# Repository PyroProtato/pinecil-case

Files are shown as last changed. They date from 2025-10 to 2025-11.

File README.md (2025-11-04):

# Pinecil Case






A 3D printed case for my pinecil with a few unique features! Uses magnets for closing, paper clips as hinges, and the rest is fully 3D-printed.

I wanted to make this project because I haven't really experimented with snap-fit parts, clean designs, and printabiility in my 3D models thus far since most of them are practical. So, to practice these skills, I decided to design and make a case for my pinecil (which I needed to do anyway). I specifically ensured that no weird parts were used (besides filament only paper clips and magnets). 

 ## BOM:
- (1x) Case Top [3D-Printed]
- (1x) Case Bottom [3D-Printed]
- (2x) Pinecil Clip [3D-Printed]
- (1x) Pinecil Logo [3D-Printed]
- (1x) Pinecil Border [3D-Printed]
- (1x) Standard Paper Clip
- (4-8x) 5mm diameter 2.8mm height magnet

 ## Creation Instructions
3D print all of the STEP files located in the 3DPRINT folder. Make sure that the layer height is set to 0.1mm for the case top and case bottom. Afterwards, assemble by cutting, inserting, and bending paper clips in the hinges, gluing logo and border onto the top case, gluing magnets into the provided holes, and gluing the clips into the indentations on the bottom case. Let it dry, and then the case is done!

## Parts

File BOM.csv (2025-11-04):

Amount | Part Name | Fabrication Method
(1x) | Case Top | [3D-Printed]
(1x) | Case Bottom | [3D-Printed]
(2x) | Pinecil Clip | [3D-Printed]
(1x) | Pinecil Logo | [3D-Printed]
(1x) | Pinecil Border | [3D-Printed]
(1x) | Standard Paper Clip | N/A
(4-8x) | 5mm diameter 2.8mm height magnet | N/A

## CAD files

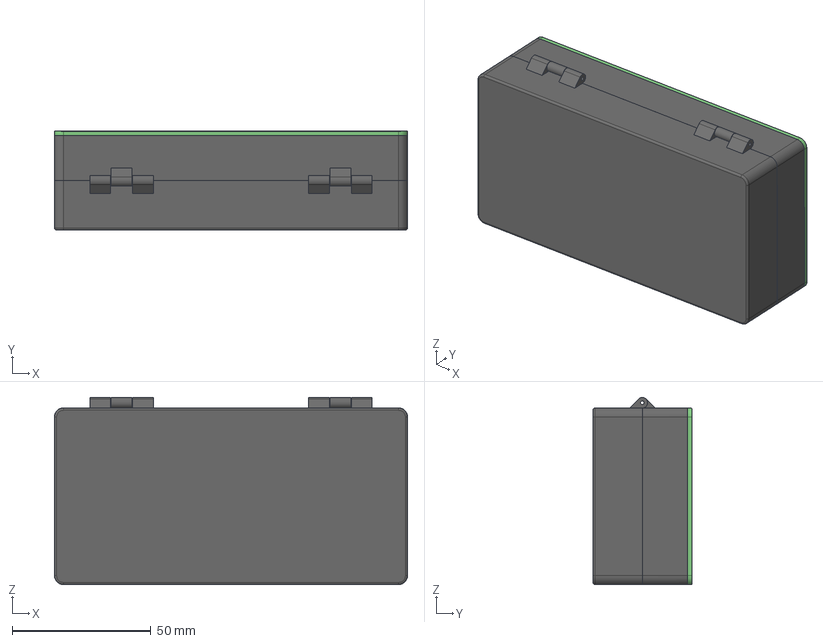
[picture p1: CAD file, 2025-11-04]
PinecilCaseASM.stp
127.0 x 35.7 x 67.3 mm
PinecilCaseBottom
Pinecil Clip x 2
PinecilCaseTop
PinecilLogo
PinecilCaseBorder

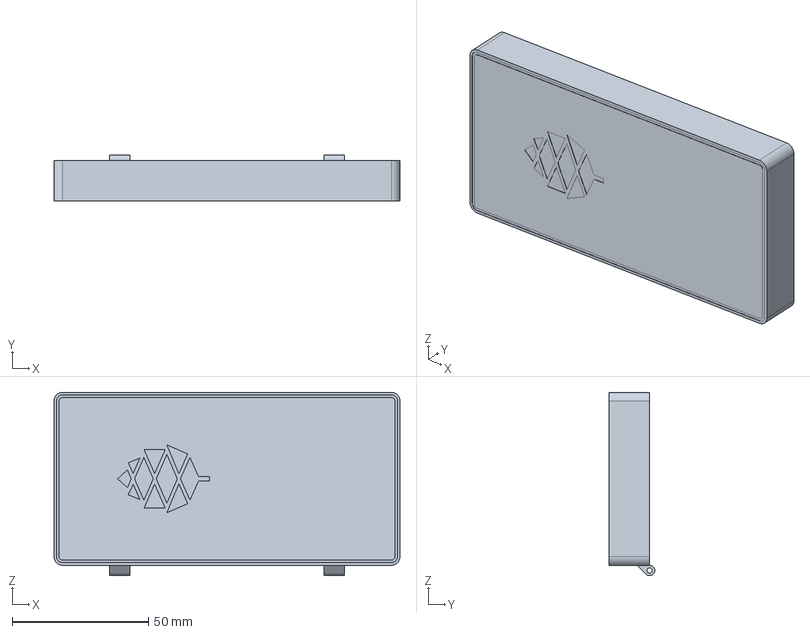
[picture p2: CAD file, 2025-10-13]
3D Print Tests/PinecilCaseTop.stp
127.0 x 16.8 x 67.3 mm

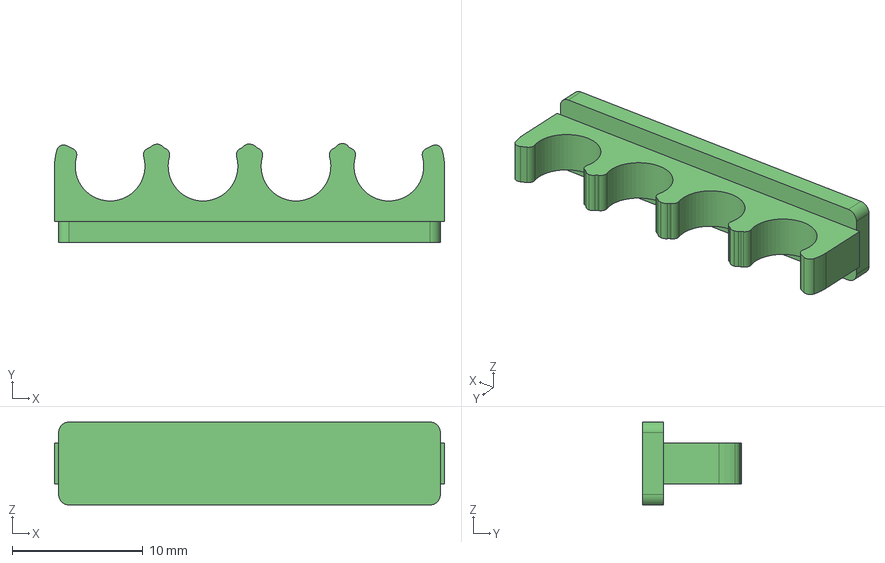
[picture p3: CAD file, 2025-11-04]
3DPRINT/Pinecil Clip.stp
29.8 x 7.57 x 6.35 mm

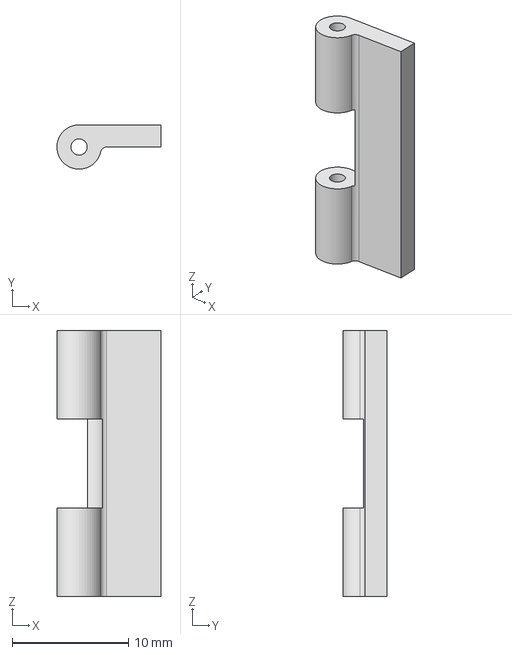
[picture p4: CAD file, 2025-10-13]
Hinge Test/3dp/outerhinge3.stp
8.95 x 3.81 x 22.9 mm

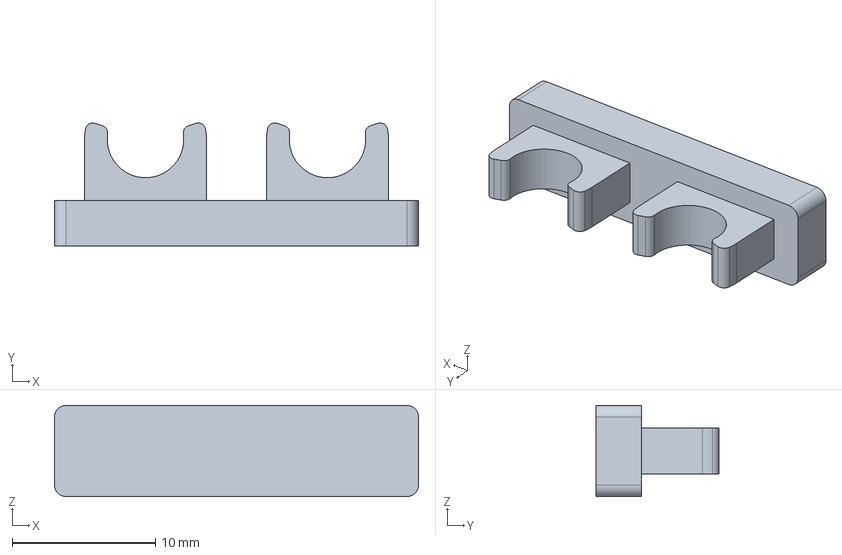
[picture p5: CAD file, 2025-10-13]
3D Print Tests/Pinecil Clip v6.stp
25.4 x 8.58 x 6.35 mm

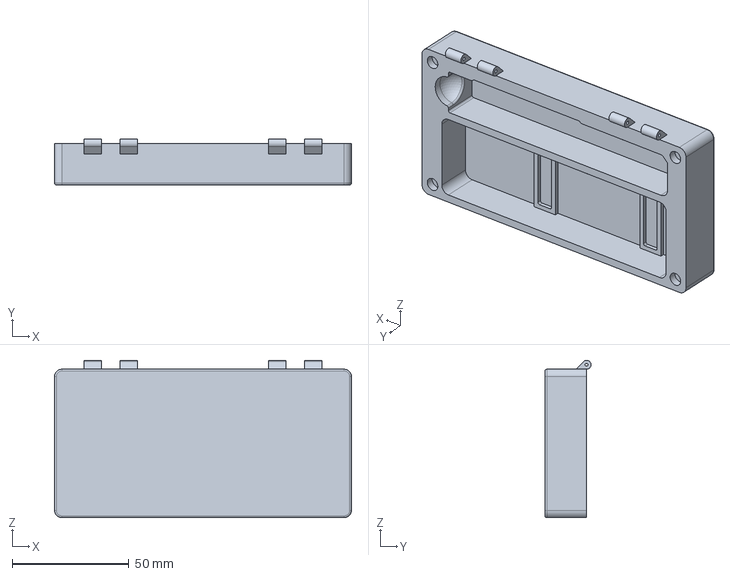
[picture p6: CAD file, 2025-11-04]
3DPRINT/PinecilCaseBottom.stp
127.0 x 19.7 x 67.3 mm

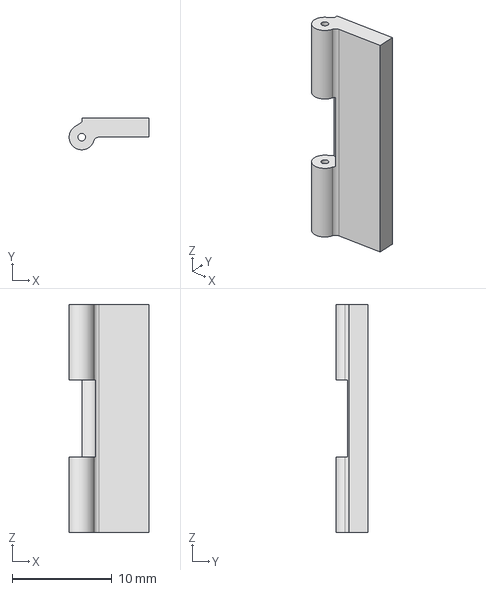
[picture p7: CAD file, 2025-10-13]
Hinge Test/3dp/outerhinge.stp
8.00 x 3.17 x 22.9 mm

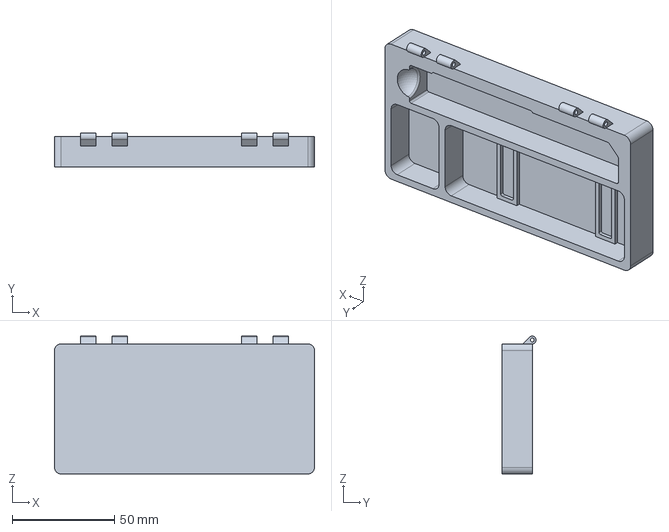
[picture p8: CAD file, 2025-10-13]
3D Print Tests/PinecilCaseBottom.stp
127.0 x 16.8 x 67.3 mm

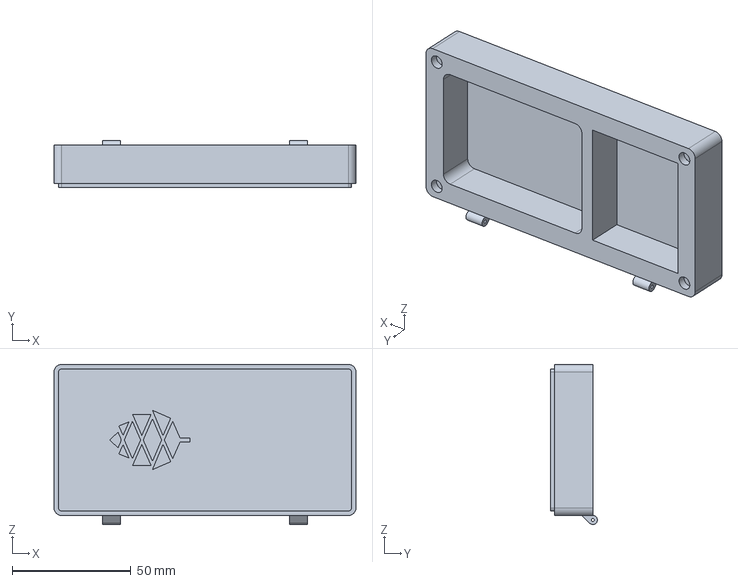
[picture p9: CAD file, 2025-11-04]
3DPRINT/PinecilCaseTop.stp
127.0 x 19.7 x 67.3 mm

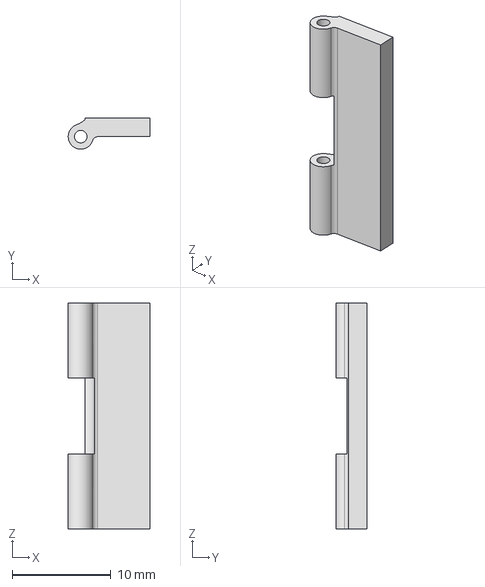
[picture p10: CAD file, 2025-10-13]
Hinge Test/3dp/outerhinge2.stp
8.25 x 3.17 x 22.9 mm

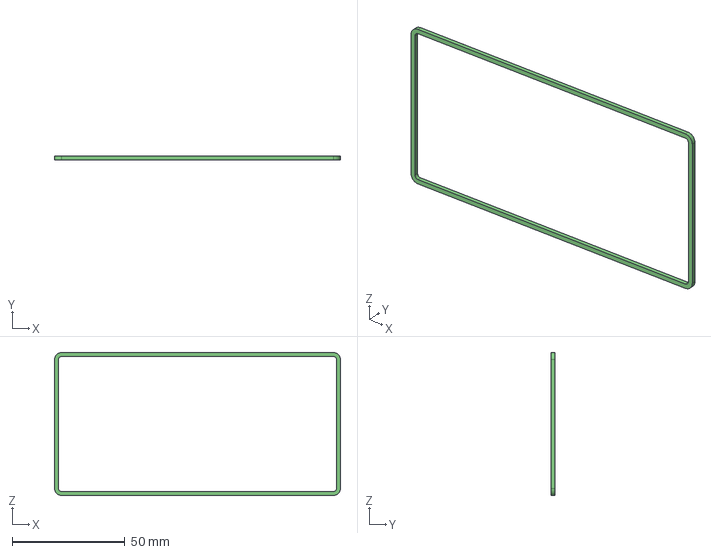
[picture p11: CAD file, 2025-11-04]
3DPRINT/PinecilCaseBorder.stp
127.0 x 1.59 x 63.5 mm

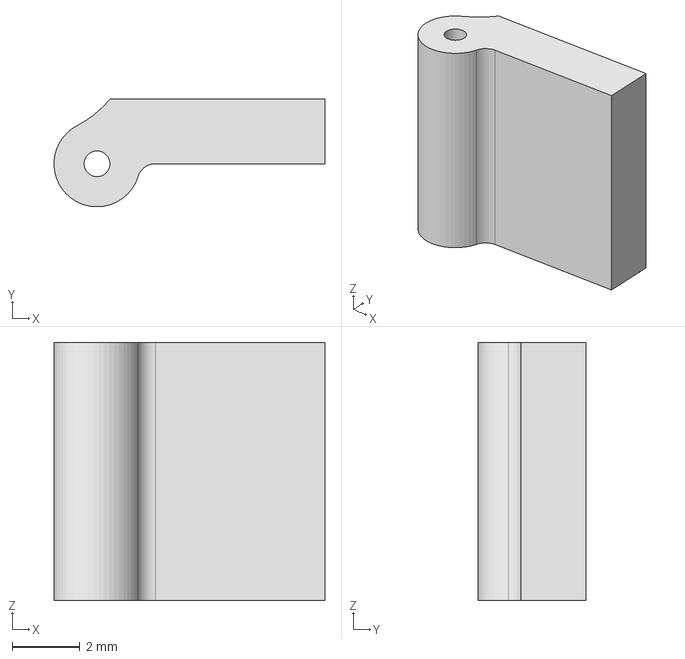
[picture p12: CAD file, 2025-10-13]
Hinge Test/3dp/innerhinge.stp
8.00 x 3.17 x 7.62 mm

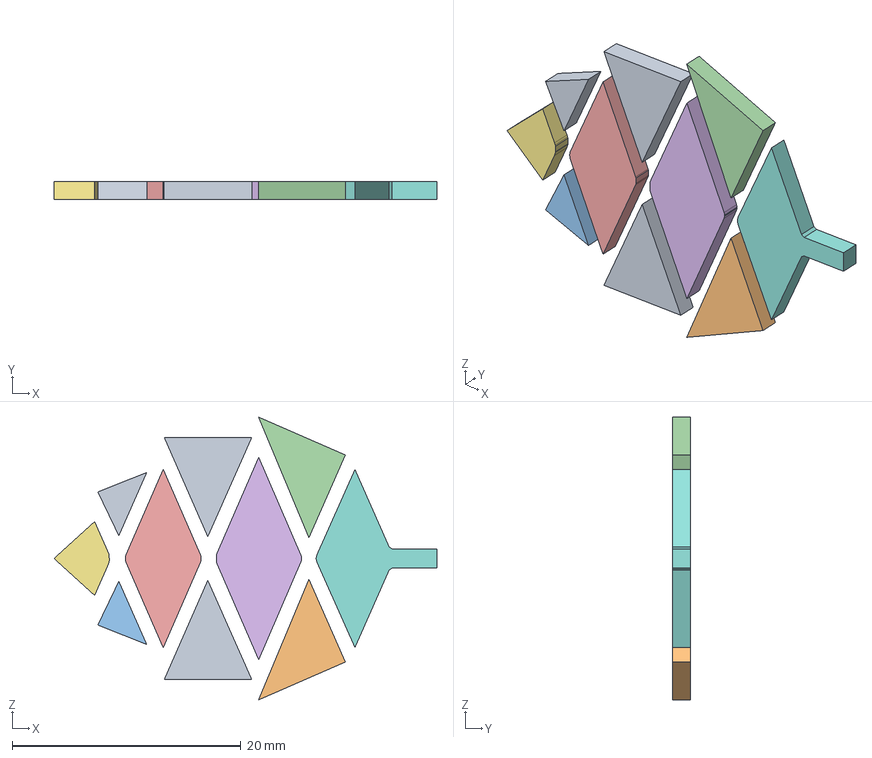
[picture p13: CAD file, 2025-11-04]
3DPRINT/PinecilLogo.stp
33.5 x 1.59 x 24.7 mm

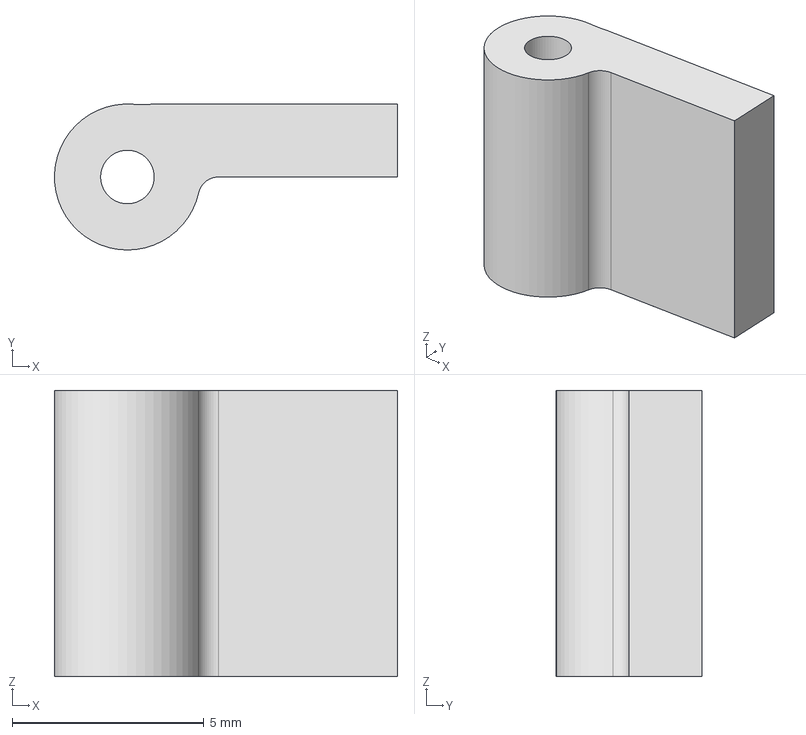
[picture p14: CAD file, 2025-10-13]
Hinge Test/3dp/innerhinge3.stp
8.95 x 3.81 x 7.47 mm

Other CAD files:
Hinge Test/3dp/innerhinge2.stp
3D Print Tests/Pinecil Clip.stp
3D Print Tests/Pinecil ClipV3.stp
3D Print Tests/Pinecil Clip V4.stp
3D Print Tests/Pinecil Clip V2.stp
3D Print Tests/Pinecil Clip V5.stp
3D Print Tests/Pinecil Clip.3mf
3D Print Tests/PinecilCaseBottom.3mf
Hinge Test/HingeAssembly.iam
Hinge Test/OldVersions/HingeAssembly.0005.iam
Hinge Test/OldVersions/innerhinge.0004.ipt
Hinge Test/OldVersions/outerhinge.0006.ipt
Hinge Test/innerhinge.ipt
Hinge Test/outerhinge.ipt
OldVersions/Pinecil Clip.0006.ipt
OldVersions/PinecilCaseASM.0016.iam
OldVersions/PinecilCaseBorder.0004.ipt
OldVersions/PinecilCaseBottom.0016.ipt
OldVersions/PinecilCaseTop.0010.ipt
OldVersions/PinecilLogo.0004.ipt
Pinecil Clip.ipt
PinecilCaseASM.iam
PinecilCaseBorder.ipt
PinecilCaseBottom.ipt
PinecilCaseTop.ipt
PinecilLogo.ipt

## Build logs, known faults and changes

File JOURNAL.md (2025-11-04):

<!--
  ===================    !!READ THIS NOTICE!!   ====================
  DO NOT edit this file manually. Your changes WILL BE OVERWRITTEN!
  This journal is auto generated and updated by Hack Club Blueprint.
  To edit this file, please edit your journal entries on Blueprint.
  ==================================================================
-->

## 10/9/2025 - Created the Bottom Case in CAD  

Screenshot 2025-10-09 112841.png
Screenshot 2025-10-09 113629.png
Screenshot 2025-10-09 113613.png

I measured out each dimension for the pinecil and tried to make a compartment that would fit it perfectly (so that it wouldn't jiggle around in the case). Additionally, I tried to design the case so that it has hotswappable clips for different pinecil tips. Each clip has a similar bottom that should fit perfectly in the slot in the case. Now to check if the clips actually fit with the pinecil tips...  

## 10/10/2025 - Tested Clips & Hinges + Designed Outside of Top Case  

Screenshot 2025-10-10 172732.png
Screenshot 2025-10-10 172720.png

First of all, I tested a bunch of different tolerances to get the perfect snap fit for the pinecil tip clips. After 6 tries I got a good one.

For the hinges, I was thinking that I wanted this case to be strong and I want the hinges to be small to make it asthetically pleasing. So, I probably wouldn't be able to use PLA for the entire hinge because it isn't the strongest and it doesn't print that well with smaller pieces. So, I was thinking of small items I could use for the axle, and I thought of a paper clip. The metal wire is pretty strong, I can cut it into smaller pieces, and it should be able to work with PLA hinges. I printed out a few tries, and it actually ended up working! So, I will use this on the final design.

Finally, I designed the outside of the top case. I want the outside to be as sleek and professional as I can, so I put their minimal logo on the front as well as a green border. Both the logo and the border I plan to print separately and glue on later to remove the need for support material (which would scar the face of the case).

## 11/2/2025 - Touch Ups (A lot of them) + Printed Main Body of Case  

Welp quite a few things were needed to be changed with the CAD. First of all, the green bordering had to be changed to print better, the clips inside to hold the soldering iron tips were changed to be able to hold 4, the top case now has sections, the bottom case now is sectioned off better, the holes for the paper clips had to be tigheter to prevent rattling, the thickness of the case and the whole pinecil spot had to be changed to fit better, and finally, I added magnet holes to the inside of the case.



I also started printing the case. The first iteration of the bottom case didn't work, so I had to reprint. However, the second try of the bottom case and the first try of the top case worked very well, so I'm pretty happy about that. Had to cut paper clips to make hinges for the case. There's still a few more touch ups needed for the case to be printed including the accents, clips, and magnets, but I will work on that in the coming week.





## 11/3/2025 - Finished Accents + Clips  

Finishing touches on the case! I glued the logo and accents onto the case, and I attached the hooks to hold the soldering tip. Also had to use pliers to cut and attach the hinges for the case. Still waiting for magnets to arrive on Amazon, but for now I think it's good enough to ship!



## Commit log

2025-10-09 Finished Bottom Case Prototype
    [Pinecil Clip.0002.ipt, Pinecil Clip.ipt, PinecilCaseASM.0002.iam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]
2025-10-13 Journal 2 and a bit of Journal 3
    [HingeAssembly.0005.iam, HingeAssembly.iam, Pinecil Clip V2.stp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]
2025-11-03 (#3) Touch Ups and Print!
    [PinecilCaseASM.0011.iam, PinecilCaseASM.0014.iam, PinecilCaseASM.iam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]
2025-11-04 Polishing Commit 1
    [Pinecil Clip V2.stp, Pinecil Clip V4.stp, Pinecil Clip V5.stp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]
2025-11-04 Polishing 2
    [PinecilCaseASM.stp]
